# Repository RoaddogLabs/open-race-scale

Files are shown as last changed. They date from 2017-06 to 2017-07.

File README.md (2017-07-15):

# open-race-scale
# 
This is the Roaddog Labs fork of Open Race Scale, the open hardware
race car scale from Andrew Jenkins at
https://github.com/jenkinsracing/open-race-scale used under OSHWA and
LGPL 3.0 license.  [Original README.md](orig_README.md)

This fork deals with hardware implementation, hardware packaging and
PCB/PCBA design and fabrication.  This fork uses the software/firmware
from the upstream fork.  Please issue software/firmware pull requests to
the upstream repo.  Pull requests for hardware implementation in this
fork are more than welcome.

The `electrical` dir contains circuit designs and PCB/PCBA info.  It
includes the reference design from the upstream master that uses Chengbo HX711 carriers, a Pi Zero W
based control board with integrated HX711 load cell amps (no carriers) and Pi Hat design using Sparkfun HX711 formfactor carriers.

The `mechanical` dir contains a reference scale pad design and enclosure designs for the various controller boards.

Original designs from Roaddog Labs Ltd are released per the Open Source
Hardware Association guidelines for open source hardware at
http://www.oshwa.org/definition/.

Material specific to the components and documentation that is not
derived from other sources are released under the Creative Commons
Attribution 4.0 International license.

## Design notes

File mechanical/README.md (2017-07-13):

### Open Race Scale Mechanical Parts

This includes a 3D printed enclosure for the Open Race Scale control board as well as scale pads.

***THIS DESIGN IS NOT YET VALIDATED***

Forked from https://github.com/jenkinsracing/open-race-scale by Andrew Jenkins license OSHW/public domain, software LGPL 2.0.

Original designs from Roaddog Labs Ltd are released per the Open Source
Hardware Association guidelines for open source hardware at
http://www.oshwa.org/definition/.

Material specific to the components and documentation that is not
derived from other sources are released under the Creative Commons
Attribution 4.0 International license.

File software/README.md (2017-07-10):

### This is the Roaddog Labs fork of Open Race Scale

Current hardware deployment is Raspbian Jesse built for arm7l.  Install using current release (or NOOBS) and run `sudo apt-get update`.  Reminder: Raspbian requires root to install, use sudo. 

Using default user pi code is deployed to ~pi, adjust your PYTHONPATH accordingly

This release requires python3, dependencies to be built with python3

Change bool value of sim to False  `sim = False` in main.py to deploy on
RPi hardware.  Hardware integration is currently in development, in run mode there may be fatal errors.

The software is currently designed in two parts. 1. Core - The core code
runs on the RPi3 and communicates with HX711 to receive weights from the
loadcells. It does limited calculations with those weights to give
standard weighing information. This data (will be) published to a
Bluetooth RFComm channel for clients to read. 2. App - The app code at
this time runs a local GUI which instantiates the core code. Bluetooth
is currently not implemented, however in the future this code will be
reused in two ways: local mode for a GUI running on the same RPi3 that
is connected to the loadcells, and client mode where the app will
operate as a Bluetooth client on a smart phone.

Core Dependencies: 

pybluez

App Dependencies:

kivy 

pygame, python3 version in Raspbian dist

cython

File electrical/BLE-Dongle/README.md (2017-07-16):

# open-race-scale
# 

This is a Bluetooth LE dongle that transmits data from the scale pad to the mobile device.

There is no software or firmware at this time.  This is a reference design using an Adafruit Bluefruit nRF52 module and a Chenbo HX711 module.  This board uses pins A0 for the d_out from the HX711 and pin A1 for the S_CLK to the HX711.  If/when this changes in the software the board will be updated.

This is the Roaddog Labs fork of Open Race Scale, the open hardware
race car scale from Andrew Jenkins at
https://github.com/jenkinsracing/open-race-scale used under OSHWA and
LGPL 3.0 license.  

Original designs from Roaddog Labs Ltd are released per the Open Source
Hardware Association guidelines for open source hardware at
http://www.oshwa.org/definition/.

Material specific to the components and documentation that is not
derived from other sources are released under the Creative Commons
Attribution 4.0 International license.

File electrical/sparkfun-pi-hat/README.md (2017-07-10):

### Open Race Scale Sparkfun HX711 carrier board control board

***THIS BOARD IS NOT YET VALIDATED***

This is an early release version of the control board using Sparkfun HX711 carriers ( https://www.sparkfun.com/products/13879?_ga=2.157347578.176752245.1497484451-1883676811.1497484451 ).  It is not yet ready for production.  It has passed Eagle ERC and DRC for Seeed Fusion PCB.

Forked from https://github.com/jenkinsracing/open-race-scale by Andrew Jenkins license OSHW/public domain, software LGPL 2.0.

Original designs from Roaddog Labs Ltd are released per the Open Source
Hardware Association guidelines for open source hardware at
http://www.oshwa.org/definition/.

Material specific to the components and documentation that is not
derived from other sources are released under the Creative Commons
Attribution 4.0 International license.

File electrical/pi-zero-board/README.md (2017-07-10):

### Open Race Scale Pi Zero based control board

***THIS BOARD IS NOT YET VALIDATED***

This is an early release version of the integrated control board.  It is not yet ready for production.  It has passed Eagle ERC and DRC for Seeed Fusion PCB.

Forked from https://github.com/jenkinsracing/open-race-scale by Andrew Jenkins license OSHW/public domain, software LGPL 2.0.

Uses Pi Zero and integrated HX711 amps instead of Pi 3 and HX711 carrier
boards.

HX711 circuit from Sparkfun Load Cell Amplifier https://github.com/sparkfun/HX711-Load-Cell-Amplifier/tree/V_1.1 license public domain/OSHW

Original designs from Roaddog Labs Ltd are released per the Open Source
Hardware Association guidelines for open source hardware at
http://www.oshwa.org/definition/.

Material specific to the components and documentation that is not
derived from other sources are released under the Creative Commons
Attribution 4.0 International license.

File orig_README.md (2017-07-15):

# open-race-scale
### Open Source Racecar Scale  
Four load cell scale controller for weighing cars using HX711 load cell module and Raspberry Pi platform. User interface will be via Bluetooth and smart phone app. The overall cost target goal for a complete car weighing system is under $230, at least 75% cheaper than commerically available car scales.
  
### Roadmap  
* Prototype electrical design as Raspberry Pi 3 Hat -> in progress  
* Create simple mechanical design for load cells -> in progress  
* Create Android/iOS app that will connect to the Rasberry Pi 3 to reccive live scale data (via bluetooth)  
* Add advanced features for storing weights for comparision  
* Add option of LCD screen directly on the Raspberry Pi 3  
* Get feedback and feature requests  
  
### Design
Electrical Design

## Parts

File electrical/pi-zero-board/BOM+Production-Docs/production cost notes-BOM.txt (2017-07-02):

BOM for open race scale pi zero board with and without carriers

Partlist exported from /Users/dave/Documents/SparkFun_HX711_Load_Cell_v11/SparkFun_HX711_Load_Cell_v11.sch at 6/15/17 5:34 PM

Part      Value                      Device                     Package                           Description                          PROD_ID     VALUE   
4xC1        0.1uF                      0.1UF-25V-5%(0603)         0603-CAP                          CAP-08604                            CAP-08604   0.1uF   
4xC2        0.1uF                      0.1UF-25V-5%(0603)         0603-CAP                          CAP-08604                            CAP-08604   0.1uF   
4xC3        0.1uF                      0.1UF-25V-5%(0603)         0603-CAP                          CAP-08604                            CAP-08604   0.1uF   
4xC4        0.1uF                      0.1UF-25V-5%(0603)         0603-CAP                          CAP-08604                            CAP-08604   0.1uF   
4xC5        0.1uF                      0.1UF-25V-5%(0603)         0603-CAP                          CAP-08604                            CAP-08604   0.1uF   
4xC6        10uF                       10UF50V20%(1210)           1210                              CAP-09824                            CAP-09824   10uF    
4xC7        10uF                       10UF50V20%(1210)           1210                              CAP-09824                            CAP-09824   10uF    
4xJ1                                   M05PTH                     1X05                              Header 5                                                 
4xJP2                                  M02PTH                     1X02                              Standard 2-pin 0.1" header. Use with                     
4xJP4                                  M05PTH                     1X05                              Header 5                                                 
4xL1        3.3uH                      INDUCTOR0805-IND           0805                              Inductors                            NDUC-13076          
4xQ1        MMBT4403                   TRANSISTOR_PNPMMBT4403     SOT23-3                           Generic PNP BJT                      TRANS-09245 MMBT4403
4xR1        20k                        20KOHM1/10W1%(0603)        0603-RES                          RES-09383                            RES-09383   20k     
4xR2        8.2K                       8.2KOHM-1/10W-5%(0603)     0603-RES                          RES-10646                            RES-10646           
4xR3        100                        100OHM-1/10W-1%(0603)      0603-RES                          RES-07863                            RES-07863   100     
4xR4        100                        100OHM-1/10W-1%(0603)      0603-RES                          RES-07863                            RES-07863   100     
4xR5        10K                        10KOHM-1/10W-1%(0603)0603  0603-RES                          RES-00824                            RES-00824   10K     
SJ2                                  JUMPER-PAD-2-NC_BY_TRACE   PAD-JUMPER-2-NC_BY_TRACE_YES_SILK                                                          
                                                                                 
xxU1        HX711                      HX711HX711                 SO16                           Kynix http://www.kynix.com/Detail/627064/HX711.html                                        IC-12445    HX711   

Per the v1r2 board
parts kitted from Digikey for a single board (carriers) ors load cell amp #5313337 $11.03
HX711 @ .40 each from Kynix http://www.kynix.com/Detail/627064/HX711.html
pi gpio connector @1.50 ea from Adafruit  https://www.adafruit.com/product/2222 (pi zero needs 90* connector plus header pins)
4 x carrier board prototype @ .49 (panelized for 4 each per board) Seeed
1 x main board 2 layer prototype @ .49 each  Seeed

1 x main board 4 layer  @ 4.90 each  Seeed (we can cut that down with higher qty and another vendor approx $2.50 in 100 ql1ty

plug terminals are the main pain point on pricing

produced carrier boards with main board ($43.29 name brand terminals), ($21.09 import brand terminals) ($19.84 pin headers) no fab, stencil cost or shipping  (source less expensive pluggable blocks)
produced main board with import carrier boards ($40.26 name brand terminals) ($18.06 import brand terminals) ($16.81 pin headers)  minimal through hole assembly

produced integrated main board in 4 layer approx ($50 name brand terminals) ($27 import brand terminals) ($24 pin headers) no fab, stencil cost or shipping

pi zero w @10 Adafruit
pi 3 @39.95 Adafruit

pcba quotes

carriers
seeed  US$374.00 plus shipping for 100 carriers per sparkfun spec not panelized (not confirmed, no cost for hx711 and C5,C6, perhaps US$100 more)
bitelle/7pcb  US$642.27 plus shipping  for 100 carriers per sparkfun spec not panelized (not confirmed, no cost for hx711 yet)

integrated board
seeed need to finish gerber for quote
bitelle/7pcb  estimate US$ 452.76 plus shipping for 10 prototype no connectors and cost TBA on hx711.  Add US$200 for production quality.

bitelle/7pcb  estimate US$ 350.00 plus shipping for 5 prototype no connectors and cost TBA on hx711.

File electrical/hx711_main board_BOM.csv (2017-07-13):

Designator | SKU | Qty
40 pos 2 row socket header-tall | 1992 | 1 | https://www.pololu.com/product/2749 | 2.95 | 2.95
2 pos socket header 2.54mm | 1012 | 1 | https://www.pololu.com/product/1012 | 0.29 | 0.29
4 pos socket header 2.54mm | 1014 | 4 | https://www.pololu.com/product/1014 | 0.39 | 1.56
6 pos socket header 2.54m | 1016 | 4 | https://www.pololu.com/product/1016 | 0.49 | 1.96
2 pos screw terminal 3.5mm | 2444 | 8 | https://www.pololu.com/product/2444 | 0.375 | 3.00
40 pos breakaway pin header | 965 | 1 | https://www.pololu.com/product/965 | 0.75 | 0.75
2 pos shorting block 2.54mm | 970 | 4 | https://www.pololu.com/product/970 | 0.19 | 0.76
Raspberry Pi Model 3 | 3055 | 1 | https://www.pololu.com/product/2759 | 39.95 | 39.95
HX711 carrier boards | CHENBO | 4 | https://www.amazon.com/dp/B01D1FECVI/ref=cm_sw_r_cp_dp_T1_z.gozbGZ390B2 | 01.997 | 08.00
bare main board pcb | SEEED | 1 |  | .5 | 0.50

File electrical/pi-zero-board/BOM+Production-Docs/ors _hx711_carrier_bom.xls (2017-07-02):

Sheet: 4 x carriers
Digi-Key Part Number | Manufacturer | Manufacturer Part Number | Customer Reference | Quantity 1 | Quantity 2 | Quantity 3 | Mfg Std Lead Time | Description | Comments | RoHS Status | Lead Free Status | REACH Status
311-1777-1-ND | YAGEO (VA) | CC0603JRX7R8BB104 |  | 100 | 0 | 0 | 20 Weeks | CAP CER 0.1UF 25V X7R 0603 | Alternate Packaging Exists | RoHS Compliant | Lead free | Unaffected Jan-2017
311-3470-1-ND | YAGEO (VA) | CC1210ZKY5V9BB106 |  | 12 | 0 | 0 | 21 Weeks | CAP CER 10UF 50V Y5V 1210 | Alternate Packaging Exists | RoHS Compliant | Lead free | Unaffected
MMBT4403-FDICT-ND | DIODES INCORPORATED (VA) | MMBT4403-7-F |  | 10 | 0 | 0 | 12 Weeks | TRANS PNP 40V 0.6A SOT23-3 | No delivery date available | RoHS Compliant | Lead free | Unaffected Jan-2017
311-20.0KHRCT-ND | YAGEO (VA) | RC0603FR-0720KL |  | 10 | 0 | 0 | 22 Weeks | RES SMD 20K OHM 1% 1/10W 0603 | Alternate Packaging Exists | RoHS Compliant | Lead free | Unaffected Jan-2017
311-8.20KHRCT-ND | YAGEO (VA) | RC0603FR-078K2L |  | 10 | 0 | 0 | 22 Weeks | RES SMD 8.2K OHM 1% 1/10W 0603 | Alternate Packaging Exists | RoHS Compliant | Lead free | Unaffected Jan-2017
311-100HRCT-ND | YAGEO (VA) | RC0603FR-07100RL |  | 10 | 0 | 0 | 22 Weeks | RES SMD 100 OHM 1% 1/10W 0603 | Alternate Packaging Exists | RoHS Compliant | Lead free | Unaffected Jan-2017
311-10.0KHRCT-ND | YAGEO (VA) | RC0603FR-0710KL |  | 10 | 0 | 0 | 22 Weeks | RES SMD 10K OHM 1% 1/10W 0603 | Alternate Packaging Exists | RoHS Compliant | Lead free | Unaffected Jan-2017
732-5318-ND | WURTH ELECTRONICS INC | 61300511121 |  | 10 | 0 | 0 | 15 Weeks | CONN HEADER 5 POS 2.54 |  | RoHS Compliant | Lead free | Unaffected Jun-2016
732-5315-ND | WURTH ELECTRONICS INC | 61300211121 |  | 5 | 0 | 0 | 15 Weeks | CONN HEADER 2 POS 2.54 |  | RoHS Compliant | Lead free | Unaffected Jun-2016
445-6394-1-ND | TDK CORPORATION (VA) | MLZ2012A3R3WT000 |  | 5 | 0 | 0 | 10 Weeks | FIXED IND 3.3UH 450MA 340 MOHM | Alternate Packaging Exists | RoHS Compliant | Lead free | Unaffected Jan-2017
n/a | Seeed | n/a |  | 1

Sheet: seeed bom carrier
c1,c2,c3,c4,c5 | CC0603JRX7R8BB104 | 5
c6,c7 | CC1210ZKY5V9BB106 | 2
l1 | MLZ2012A3R3WT000 | 1
q1 | MMBT4403-7-F | 1
r1 | RC0603FR-0720KL | 1
r2 | RC0603FR-078K2L | 1
r3,r4 | RC0603FR-07100RL | 1
r5 | RC0603FR-0710KL | 1
u1 | hx711 | 1

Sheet: main board
ors main carrier board
 |  |  |  |  |  | revised scale pad connectors
 |  |  |  |  |  | pin headers
2 | 40 pin break away headers | pololu | 0.75 | 1.5 |  | 3 | 40 pin break away headers | pololu | 0.75 | 2.25
1 | 2 x 20 female header | adafruit | 1.5 | 1.5 |  | 1 | 2 x 20 female header | adafruit | 1.5 | 1.5
1 | 1 x 2 female header | pololu | 0.29 | 0.29 |  | 1 | 1 x 2 female header | pololu | 0.29 | 0.29
4 | 1 x 4 female header | pololu | 0.39 | 1.56 |  | 4 | 1 x 4 female header | pololu | 0.39 | 1.56
4 | 1 x 6 female header | pololu | 0.49 | 1.96 |  | 4 | 1 x 6 female header | pololu | 0.49 | 1.96
4 | jumper blocks | pololu | 0.19 | 0.76 |  | 4 | jumper blocks | pololu | 0.19 | 0.76
4 | plugable screw terminal M | Phoenix | 1.7 | 6.8 |  |  |  |  | 0 | 0
4 | plugable screw terminal F | Phoenix | 4.35 | 17.4 |  |  |  |  | 0 | 0
 |  |  |  | 0 |  |  |  |  |  | 0
 |  |  |  | 0 |  |  |  |  |  | 0
1 | board | seeed | 0.49 | 0.49 |  | 1 | board | seeed | 0.49 | 0.49
 |  |  |  | 32.26 |  |  |  |  |  | 8.81
1 | set import HX711 carriers | Amazon | 8 | 8 |  | 1 | set import HX711 carriers | Amazon | 8 | 8
 |  |  |  | 40.26 |  |  |  |  |  | 16.81
revised scale pad connectors
import 3.5 plug or screw terminals
2 | 40 pin break away headers | pololu | 0.75 | 1.5
1 | 2 x 20 female header | adafruit | 1.5 | 1.5
1 | 1 x 2 female header | pololu | 0.29 | 0.29
4 | 1 x 4 female header | pololu | 0.39 | 1.56
4 | 1 x 6 female header | pololu | 0.49 | 1.96
4 | jumper blocks | pololu | 0.19 | 0.76
4 | plugable screw terminal M | import | 0.25 | 1 | *moq
4 | plugable screw terminal F | import | 0.25 | 1 | *moq
 |  |  |  | 0
 |  |  |  | 0
1 | board | seeed | 0.49 | 0.49
 |  |  |  | 10.06
1 | set import HX711 carriers | Amazon | 8 | 8
 |  |  |  | 18.06

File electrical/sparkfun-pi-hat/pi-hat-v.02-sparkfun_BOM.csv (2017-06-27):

Designator | Pololu SKU | Qty
J1 | 1037 | 1 | https://www.pololu.com/product/1037
J2,J3,J4,J5,J6,J7,J8,J9 | 1015 | 8 | https://www.pololu.com/product/1015
J10,J11,J12,J13 | 965 | 1 | https://www.pololu.com/product/965

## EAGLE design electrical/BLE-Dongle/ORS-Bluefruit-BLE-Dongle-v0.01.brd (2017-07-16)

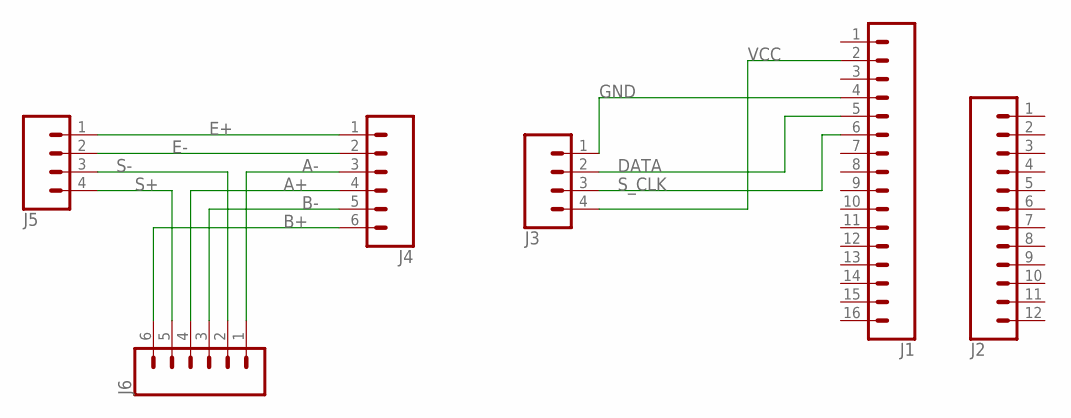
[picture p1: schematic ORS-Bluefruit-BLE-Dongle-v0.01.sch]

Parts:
J1: CONN_16; 1X16
J2: CONN_12; 1X12
J3: CONN_04; 1X04
J4, J6: CONN_06SILK_FEMALE_PTH; 1X06
J5: CONN_04SCREW; SCREWTERMINAL-3.5MM-4

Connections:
A+: J4.4, J6.4
A-: J4.3, J6.1
B+: J4.6, J6.6
B-: J4.5, J6.3
DATA: J1.5, J3.2
E+: J4.1, J5.1
E-: J4.2, J5.2
GND: J1.4, J3.1
S+: J5.4, J6.5
S-: J5.3, J6.2
S_CLK: J1.6, J3.3
VCC: J1.2, J3.4

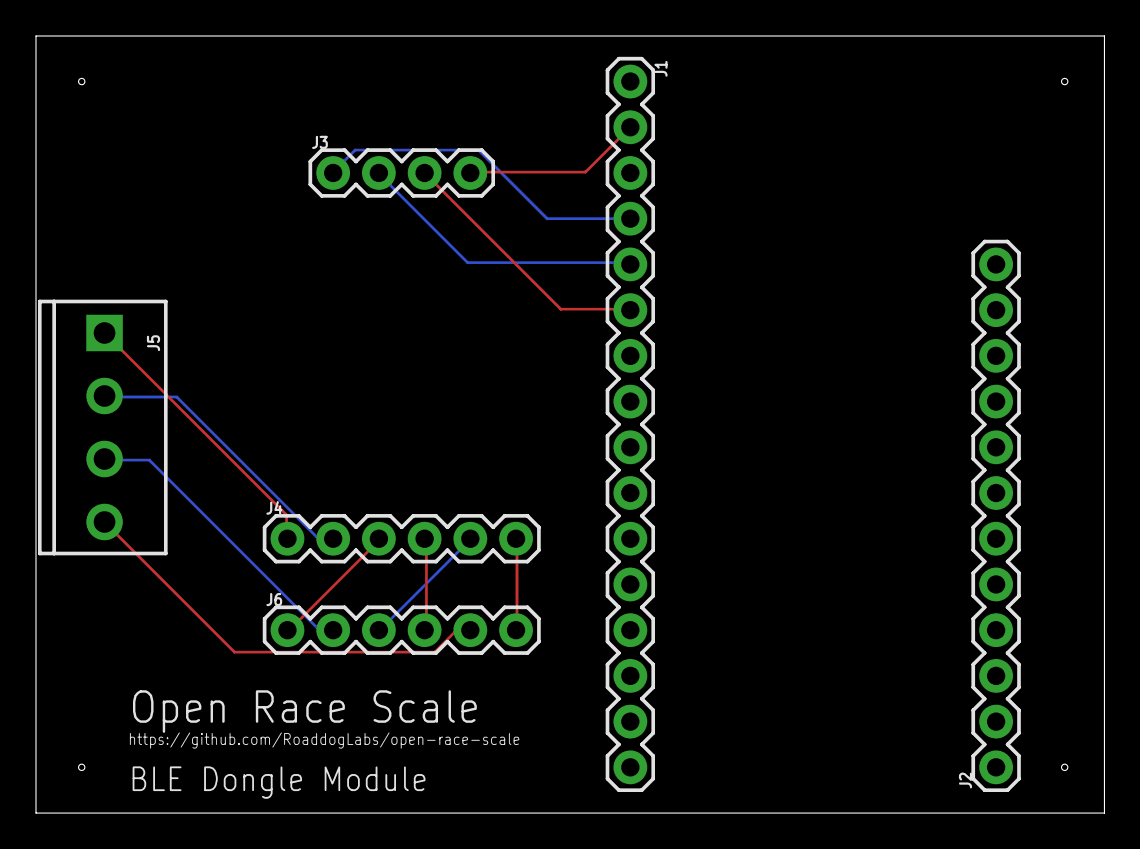
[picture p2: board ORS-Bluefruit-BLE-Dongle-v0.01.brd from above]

Board: 2 copper layers, 59.4 x 43.2 mm, 6 parts (0 on the bottom side), 12 nets.

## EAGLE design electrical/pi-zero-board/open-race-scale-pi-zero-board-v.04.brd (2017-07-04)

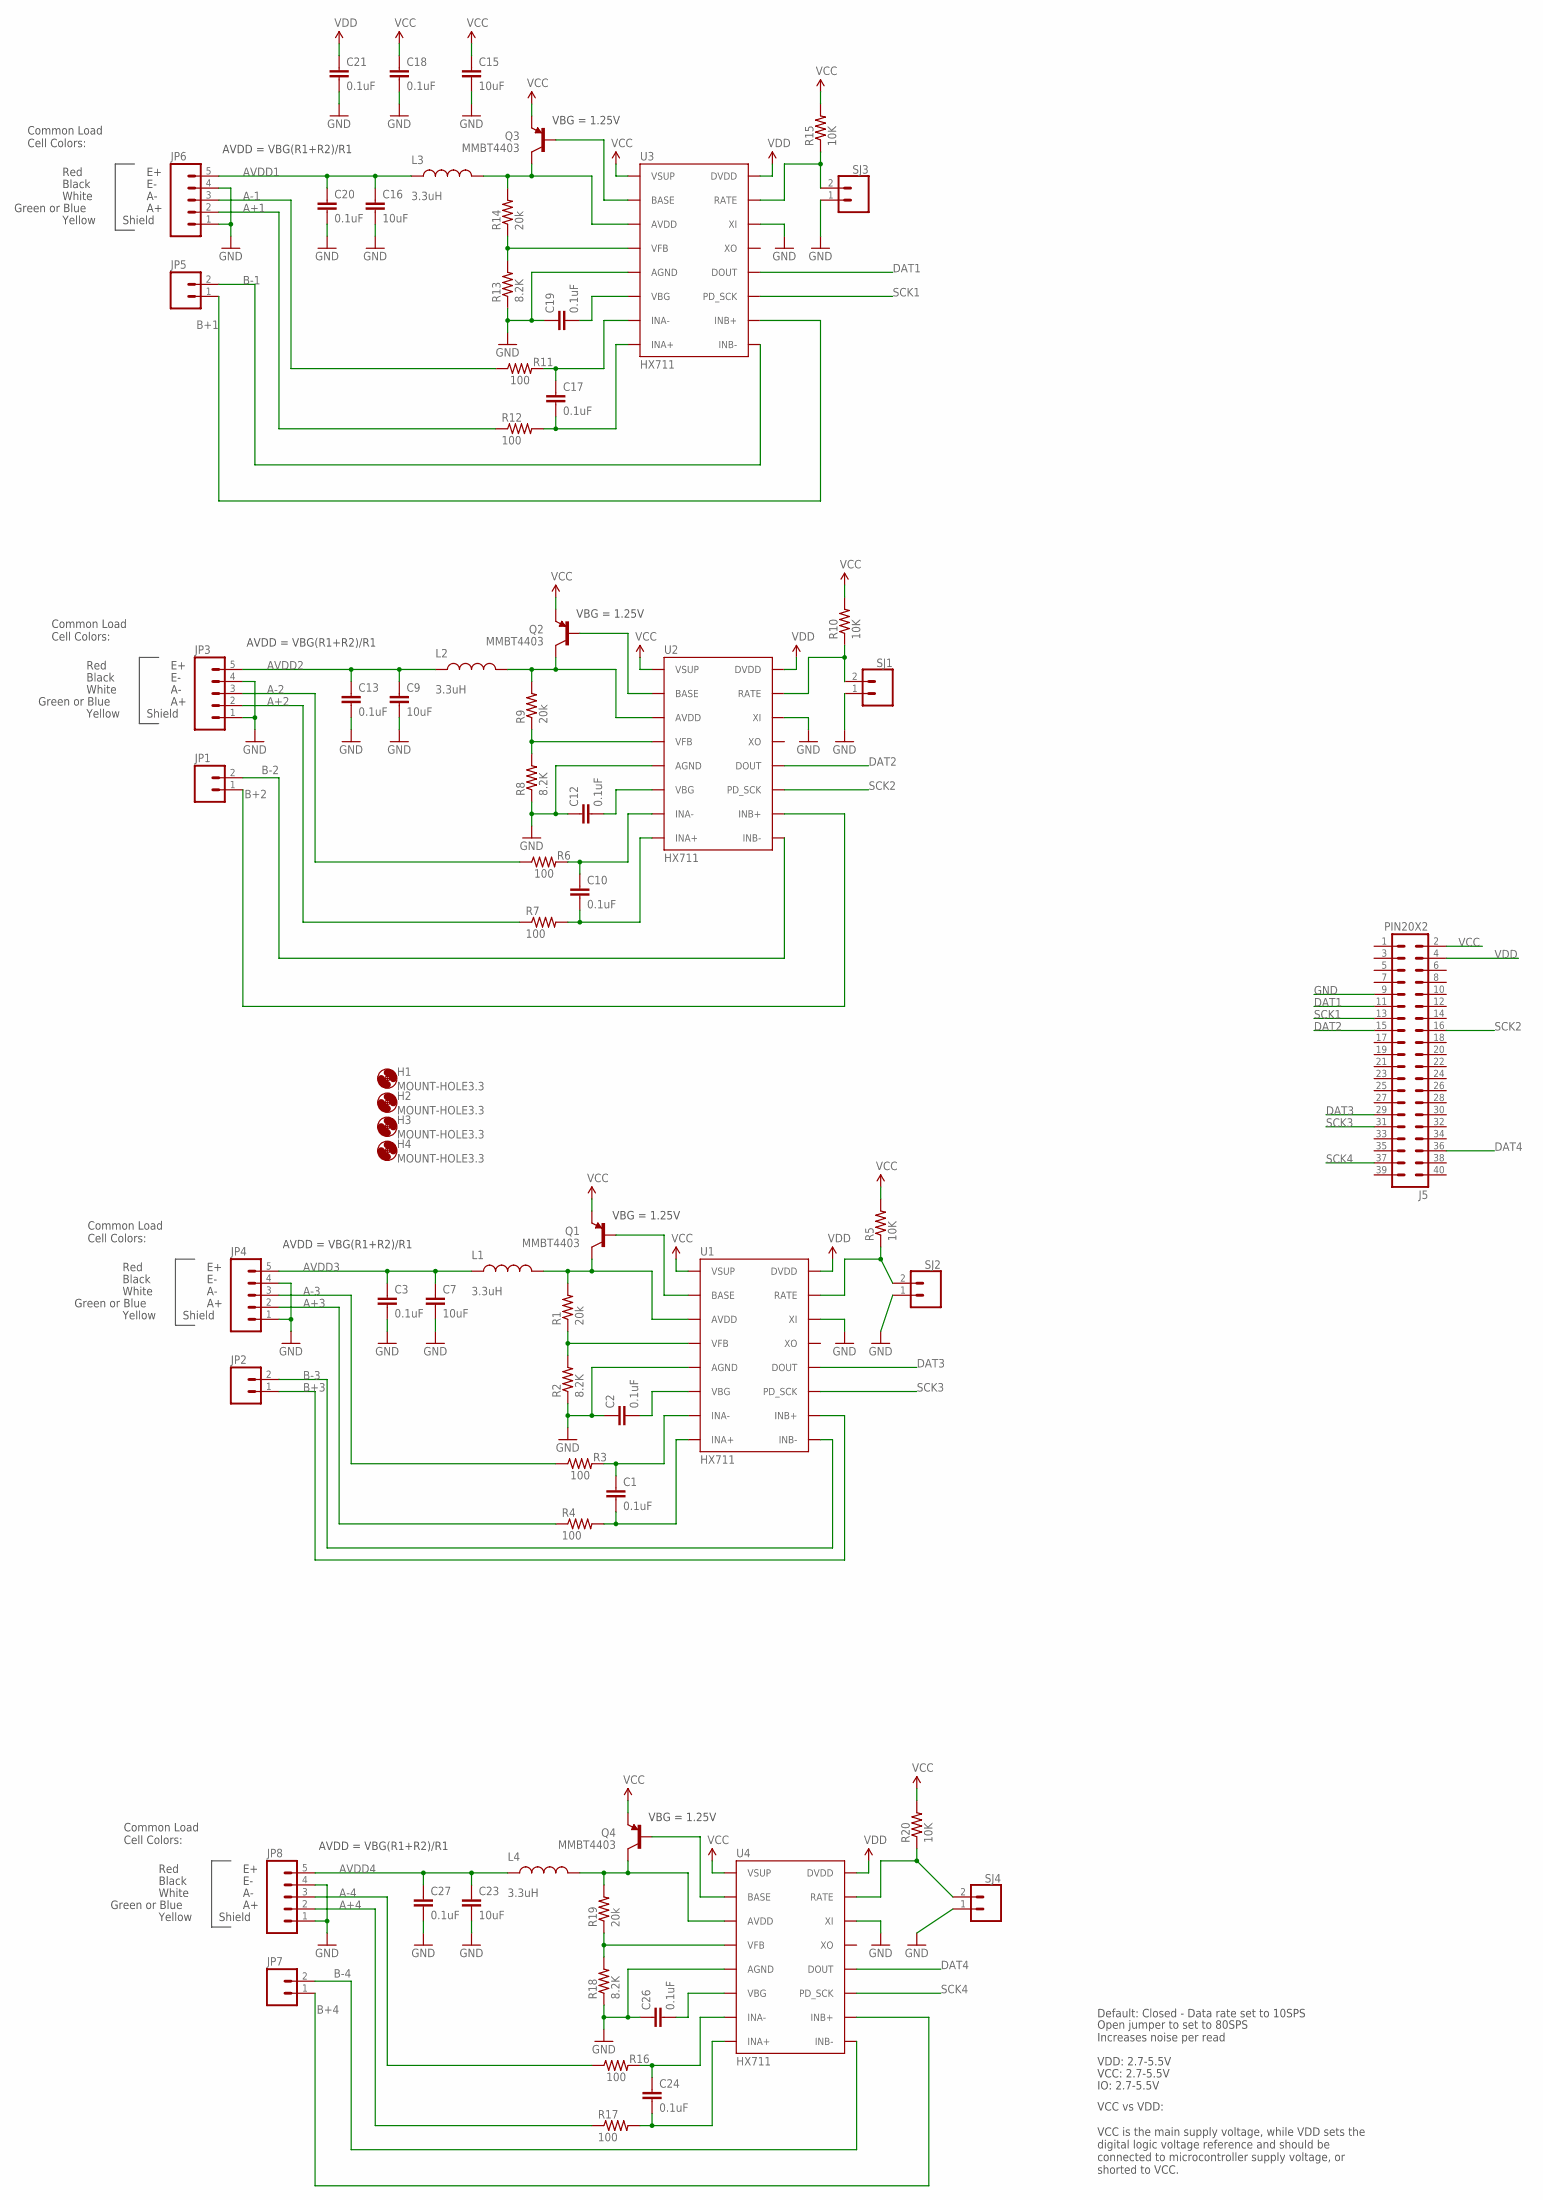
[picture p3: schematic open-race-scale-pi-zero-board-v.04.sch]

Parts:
C1, C2, C3, C10, C12, C13, C17, C18, C19, C20, C21, C24, C26, C27: 0.1uF; 0603-CAP
C7, C9, C15, C16, C23: 10uF; 1210
H1, H2, H3, H4: MOUNT-HOLE3.3; 3,3
J5: PIN20X2; PIN_20X2
JP1, JP2, JP5, JP7: M02PTH; 1X02@1
JP3, JP4, JP6, JP8: M05PTH; 1X05
L1, L2, L3, L4: 3.3uH; 0805
Q1, Q2, Q3, Q4: MMBT4403; SOT23-3
R1, R9, R14, R19: 20k; 0603-RES
R2, R8, R13, R18: 8.2K; 0603-RES
R3, R4, R6, R7, R11, R12, R16, R17: 100; 0603-RES
R5, R10, R15, R20: 10K; 0603-RES
SJ1, SJ2, SJ3, SJ4: CONN_02; 1X02
U1, U2, U3, U4: HX711; SO16

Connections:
A+1: JP6.2, R12.1
A+2: JP3.2, R7.1
A+3: JP4.2, R4.1
A+4: JP8.2, R17.1
A-1: JP6.3, R11.1
A-2: JP3.3, R6.1
A-3: JP4.3, R3.1
A-4: JP8.3, R16.1
AVDD1: C16.1, C20.1, JP6.5, L3.1
AVDD2: C9.1, C13.1, JP3.5, L2.1
AVDD3: C3.1, C7.1, JP4.5, L1.1
AVDD4: C23.1, C27.1, JP8.5, L4.1
B+1: JP5.1, U3.10 (INB+)
B+2: JP1.1, U2.10 (INB+)
B+3: JP2.1, U1.10 (INB+)
B+4: JP7.1, U4.10 (INB+)
B-1: JP5.2, U3.9 (INB-)
B-2: JP1.2, U2.9 (INB-)
B-3: JP2.2, U1.9 (INB-)
B-4: JP7.2, U4.9 (INB-)
DAT1: J5.11, U3.12 (DOUT)
DAT2: J5.15, U2.12 (DOUT)
DAT3: J5.29, U1.12 (DOUT)
DAT4: J5.36, U4.12 (DOUT)
GND: C2.1, C3.2, C7.2, C9.2, C12.1, C13.2, C15.2, C16.2, C18.2, C19.1, C20.2, C21.2, C23.2, C26.1, C27.2, J5.9, JP3.1, JP3.4, JP4.1, JP4.4, JP6.1, JP6.4, JP8.1, JP8.4, R2.1, R8.1, R13.1, R18.1, SJ1.1, SJ2.1, SJ3.1, SJ4.1, U1.5 (AGND), U1.14 (XI), U2.5 (AGND), U2.14 (XI), U3.5 (AGND), U3.14 (XI), U4.5 (AGND), U4.14 (XI)
unnamed: R5.1, SJ2.2, U1.15 (RATE)
unnamed: C1.1, R3.2, U1.7 (INA-)
unnamed: C1.2, R4.2, U1.8 (INA+)
unnamed: Q1.1 (B), U1.2 (BASE)
unnamed: L1.2, Q1.3 (C), R1.2, U1.3 (AVDD)
unnamed: R1.1, R2.2, U1.4 (VFB)
unnamed: C2.2, U1.6 (VBG)
unnamed: R8.2, R9.1, U2.4 (VFB)
unnamed: C12.2, U2.6 (VBG)
unnamed: C17.1, R11.2, U3.7 (INA-)
unnamed: C17.2, R12.2, U3.8 (INA+)
unnamed: Q4.1 (B), U4.2 (BASE)
unnamed: R18.2, R19.1, U4.4 (VFB)
unnamed: C26.2, U4.6 (VBG)
unnamed: L4.2, Q4.3 (C), R19.2, U4.3 (AVDD)
unnamed: R20.1, SJ4.2, U4.15 (RATE)
unnamed: C24.1, R16.2, U4.7 (INA-)
unnamed: C24.2, R17.2, U4.8 (INA+)
unnamed: Q2.1 (B), U2.2 (BASE)
unnamed: L2.2, Q2.3 (C), R9.2, U2.3 (AVDD)
unnamed: R10.1, SJ1.2, U2.15 (RATE)
unnamed: C10.1, R6.2, U2.7 (INA-)
unnamed: C10.2, R7.2, U2.8 (INA+)
unnamed: Q3.1 (B), U3.2 (BASE)
unnamed: R13.2, R14.1, U3.4 (VFB)
unnamed: C19.2, U3.6 (VBG)
unnamed: L3.2, Q3.3 (C), R14.2, U3.3 (AVDD)
unnamed: R15.1, SJ3.2, U3.15 (RATE)
SCK1: J5.13, U3.11 (PD_SCK)
SCK2: J5.16, U2.11 (PD_SCK)
SCK3: J5.31, U1.11 (PD_SCK)
SCK4: J5.37, U4.11 (PD_SCK)
VCC: C15.1, C18.1, J5.2, Q1.2 (E), Q2.2 (E), Q3.2 (E), Q4.2 (E), R5.2, R10.2, R15.2, R20.2, U1.1 (VSUP), U2.1 (VSUP), U3.1 (VSUP), U4.1 (VSUP)
VDD: C21.1, J5.4, U1.16 (DVDD), U2.16 (DVDD), U3.16 (DVDD), U4.16 (DVDD)

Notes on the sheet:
VBG = 1.25V
AVDD = VBG(R1+R2)/R1
Red
Black
White
Green or Blue
Common Load Cell Colors:
Shield
Yellow
VCC: 2.7-5.5V
Default: Closed - Data rate set to 10SPS
Open jumper to set to 80SPS Increases noise per read
IO: 2.7-5.5V
VDD: 2.7-5.5V
VCC vs VDD: VCC is the main supply voltage, while VDD sets the digital logic voltage reference and should be connected to microcontroller supply voltage, or shorted to VCC.

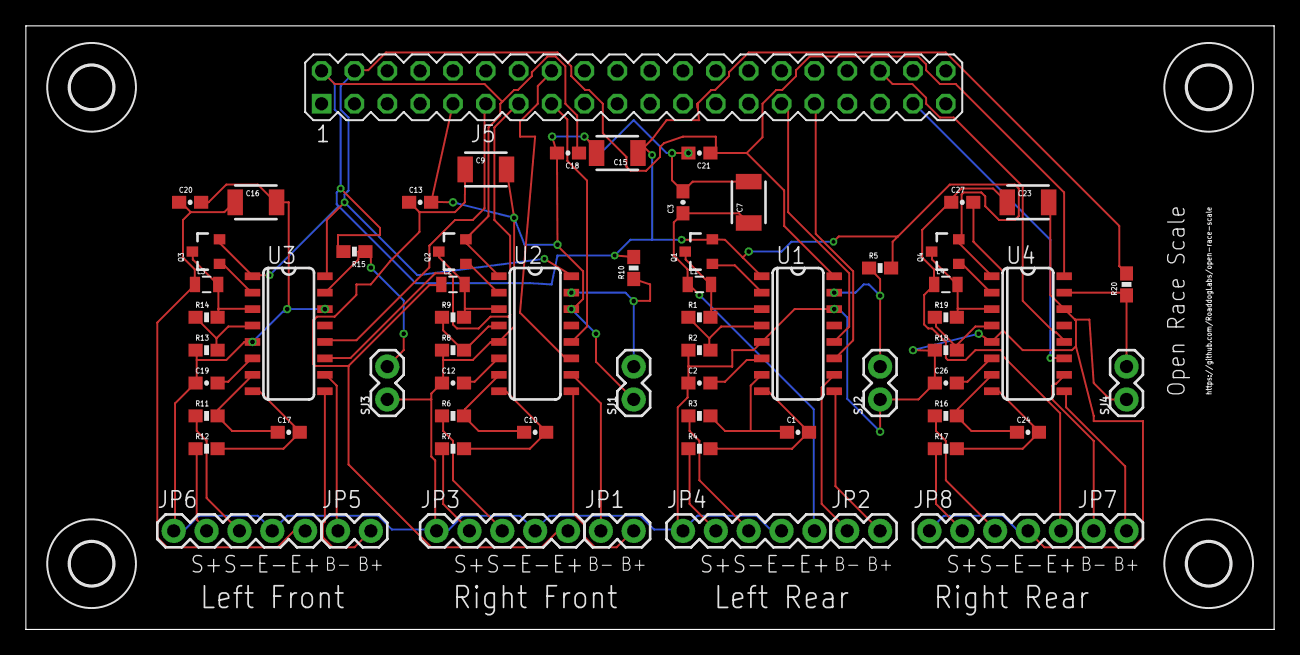
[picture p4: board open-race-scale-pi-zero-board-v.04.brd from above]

Board: 2 copper layers, 96.5 x 46.7 mm, 68 parts (0 on the bottom side), 59 nets.

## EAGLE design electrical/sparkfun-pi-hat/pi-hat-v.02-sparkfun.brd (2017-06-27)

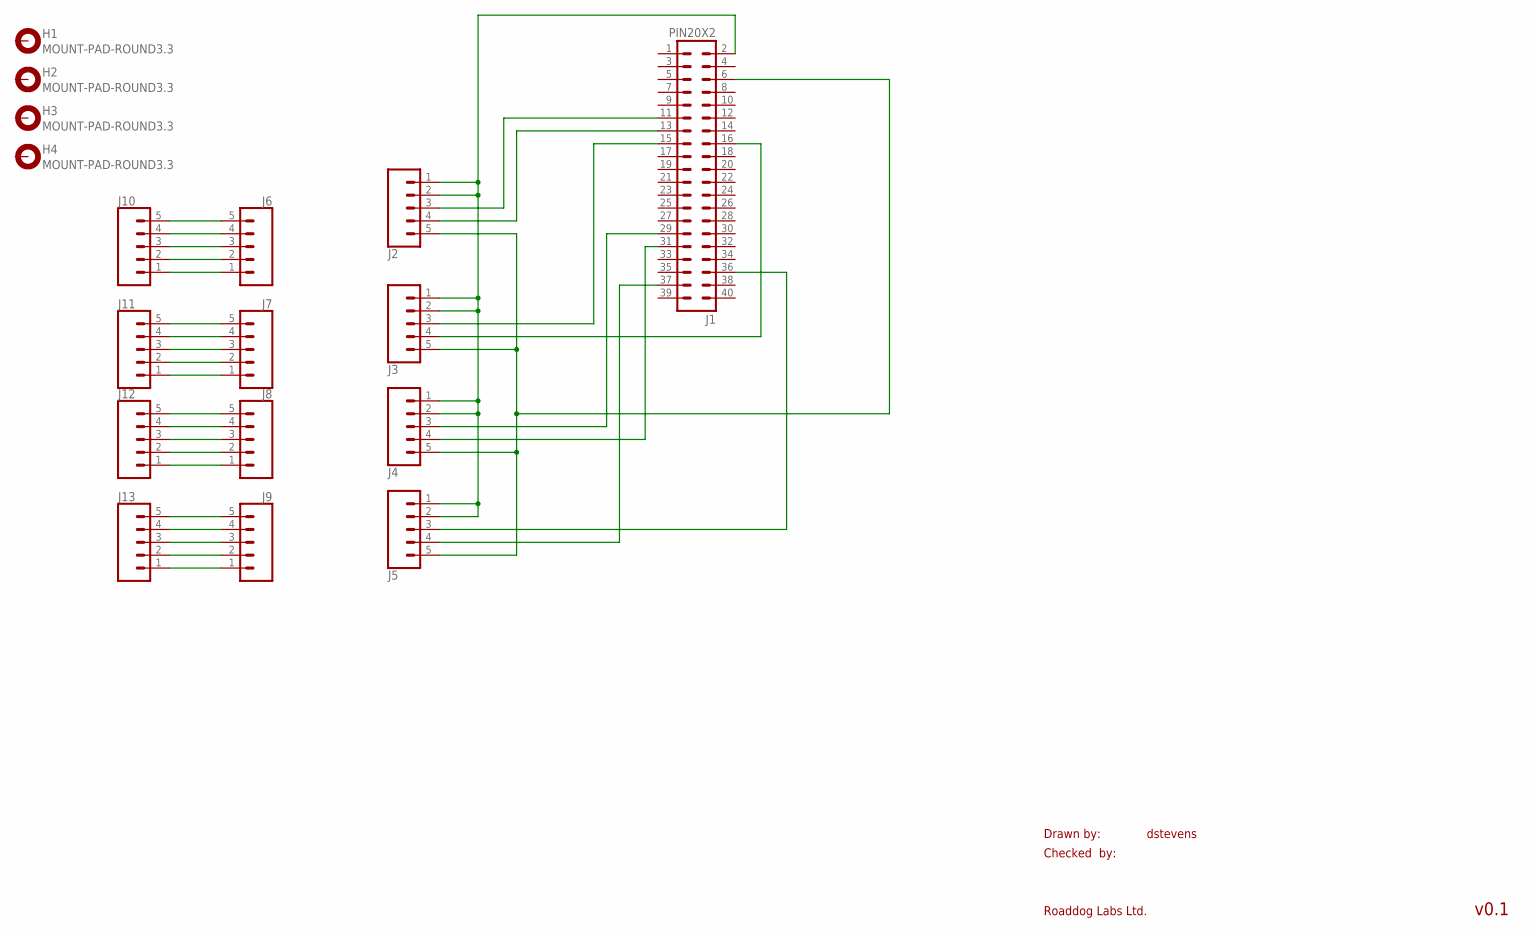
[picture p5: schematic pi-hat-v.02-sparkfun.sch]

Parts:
H1, H2, H3, H4: MOUNT-PAD-ROUND3.3; 3,3-PAD
J1: PIN20X2; PIN_20X2
J2, J3, J4, J5, J6, J7, J8, J9, J10, J11, J12, J13: CONN_05; 1X05

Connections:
unnamed: J6.5, J10.5
unnamed: J6.4, J10.4
unnamed: J6.3, J10.3
unnamed: J6.2, J10.2
unnamed: J6.1, J10.1
unnamed: J7.5, J11.5
unnamed: J7.4, J11.4
unnamed: J7.3, J11.3
unnamed: J7.2, J11.2
unnamed: J7.1, J11.1
unnamed: J8.5, J12.5
unnamed: J8.4, J12.4
unnamed: J8.3, J12.3
unnamed: J8.2, J12.2
unnamed: J8.1, J12.1
unnamed: J9.5, J13.5
unnamed: J1.2, J2.1, J2.2, J3.1, J3.2, J4.1, J4.2, J5.1, J5.2
unnamed: J1.6, J2.5, J3.5, J4.5, J5.5
unnamed: J1.11, J2.3
unnamed: J1.13, J2.4
unnamed: J1.15, J3.3
unnamed: J1.16, J3.4
unnamed: J1.37, J5.4
unnamed: J1.36, J5.3
unnamed: J1.31, J4.4
unnamed: J1.29, J4.3
unnamed: J9.4, J13.4
unnamed: J9.3, J13.3
unnamed: J9.2, J13.2
unnamed: J9.1, J13.1

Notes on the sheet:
Drawn by:
Checked by:
Roaddog Labs Ltd.
dstevens
v0.1

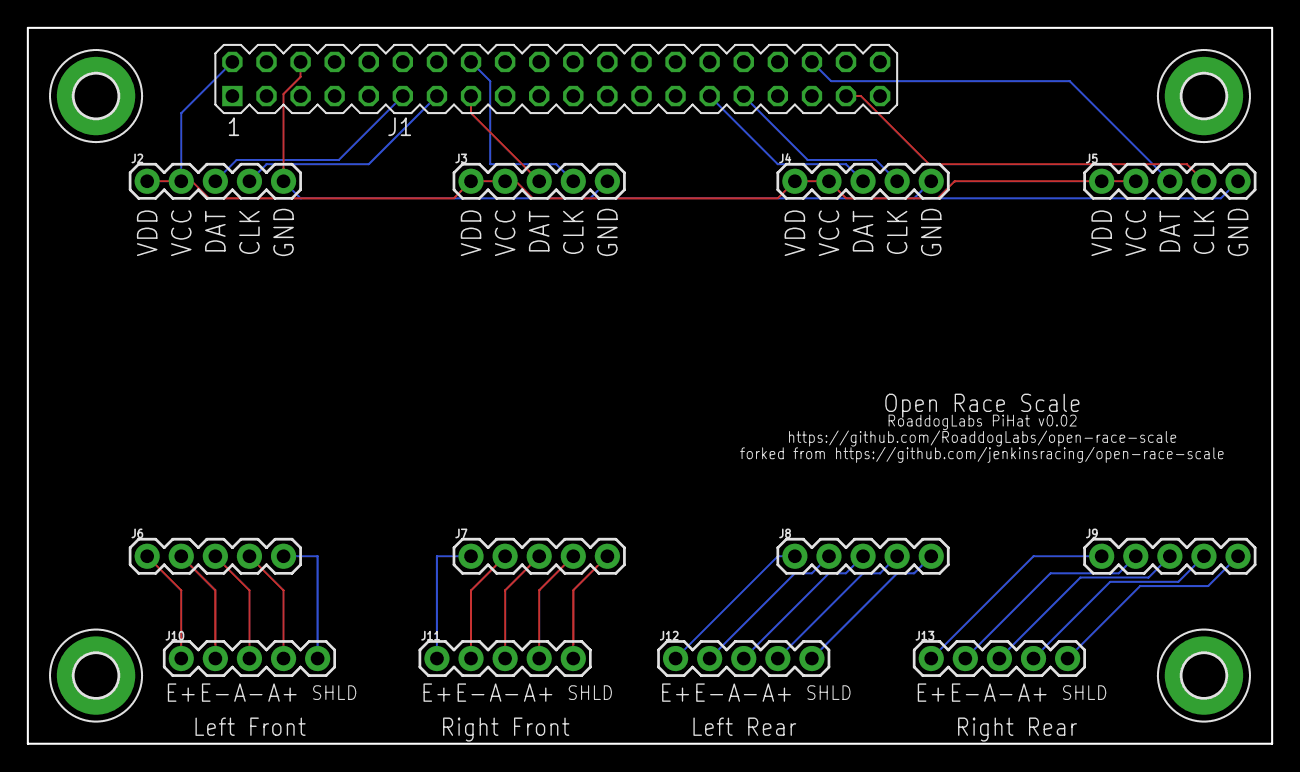
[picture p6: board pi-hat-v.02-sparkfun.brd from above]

Board: 2 copper layers, 92.7 x 53.3 mm, 17 parts (0 on the bottom side), 30 nets.

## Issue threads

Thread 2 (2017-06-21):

carrier topology needs revision to fit on pi hat

RoaddogLabs, 2017-06-21:
the Fritzing design does not fit on a spec pi hat
investigate different layout or increase pi hat size to non-standard

non-standard board will require different GPIO header to clear usb and ethernet
possible heat and rf issues in ports, investigate

pi hat specs at https://github.com/raspberrypi/hats

@jenkinsracing

[pi-hat-v.01.pdf](https://github.com/RoaddogLabs/open-race-scale/files/1090928/pi-hat-v.01.pdf)

RoaddogLabs, 2017-06-21:
resolved with jenkins fix on fritzing and dave fix on pi hat eagle

Closed 2017-06-21.

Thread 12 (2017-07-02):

pi zero board: replace sj w/ pin jumpers?

RoaddogLabs, 2017-07-02:
investigate replacing the solder jumpers with pin jumpers

RoaddogLabs, 2017-07-02:
replaced with pin jumpers
investigate different solder jumpers
sparkfun sj keep failing DRC

Closed 2017-07-04.

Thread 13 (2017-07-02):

pi zero board: jumpers for speed setting or separate connector?

RoaddogLabs, 2017-07-02:
what is the best way to use either speed channels on hx711?

jumpers like on 1st jenkins board rev

or

separate header pins like on 1st pi zero board rev

leaning toward jumpers like jenkins

RoaddogLabs, 2017-07-02:
rework design to use jumpers per jenkins design

RoaddogLabs, 2017-07-02:
check with @jenkinsracing for use cases requiring the second channel

RoaddogLabs, 2017-08-01:
will not provide access to second channel

no supporting information to support need to provide both channels

Closed 2017-08-01.

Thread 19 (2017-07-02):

pi zero board: scale sensor connectors

RoaddogLabs, 2017-07-02:
rework layout for order of connections
rework pin headers for 3.5 pitch screw terminal

RoaddogLabs, 2017-07-14:
won't fix, closing

Closed 2017-07-14.

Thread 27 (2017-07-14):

app rpi: kivy stalls when quit and relaunched

RoaddogLabs, 2017-07-14:
kivy stalls when ors page is exited on `provider sdl2`

python3 consumes 99% cpu

RoaddogLabs, 2017-07-14:
resuming with fg spawns 2 python3 procs that consume 100% cpu

resolves by killing procs or bring to foreground and exit

RoaddogLabs, 2017-07-14:
`pi@raspberrypi:~/open-race-scale/software/app $ python3 main.py
[INFO   ] [Logger      ] Record log in /home/pi/.kivy/logs/kivy_17-07-14_8.txt
[INFO   ] [Kivy        ] v1.10.1.dev0, git-287d3b6, 20170710
[INFO   ] [Python      ] v3.4.2 (default, Oct 19 2014, 13:31:11)
[GCC 4.9.1]
[INFO   ] [Factory     ] 194 symbols loaded
[INFO   ] [Image       ] Providers: img_tex, img_dds, img_sdl2, img_pil, img_gif (img_ffpyplayer ignored)
[INFO   ] [Text        ] Provider: sdl2
^C Traceback (most recent call last):
   File "main.py", line 193, in <module>
     sc = ScaleControl(simulate=sim)
   File "/home/pi/open-race-scale/software/core/corerp3.py", line 10, in __init__
     self.load_cells = {'FL': LoadCell(17, 27, simulate=simulate),
   File "/home/pi/open-race-scale/software/core/loadcell.py", line 25, in __init__
     self.driver = driver or HX711(dout_pin, pd_sck_pin)
   File "/home/pi/open-race-scale/software/core/hx711.py", line 27, in __init__
     self.set_gain(gain)
   File "/home/pi/open-race-scale/software/core/hx711.py", line 48, in set_gain
     self.read()
   File "/home/pi/open-race-scale/software/core/hx711.py", line 61, in read
     self.wait_for_ready()
   File "/home/pi/open-race-scale/software/core/hx711.py", line 51, in wait_for_ready
     while not self.is_ready():
   File "/home/pi/open-race-scale/software/core/hx711.py", line 30, in is_ready
     def is_ready(self):
 KeyboardInterrupt
[2]+  Terminated              python3 main.py`

RoaddogLabs, 2017-07-14:
can't replicate so far, did it twice but now runs

RoaddogLabs, 2017-07-15:
can't replicate over 24 hours, closing

Closed 2017-07-15.

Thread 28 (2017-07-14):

rpi hardware: exciter voltages not present on all boards

RoaddogLabs, 2017-07-14:
exciter voltages don't meter on all Chenbo boards

RoaddogLabs, 2017-07-14:
all but carrier 3 fixed, close this and open new for that one carrier

Closed 2017-07-14.

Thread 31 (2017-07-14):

rpi hardware: no exciter voltage #3

RoaddogLabs, 2017-07-14:
no exciter voltage #3

RoaddogLabs, 2017-07-15:
replaced carrier, meters voltage at e+ and e-

Closed 2017-07-15.

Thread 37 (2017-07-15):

rpi integration: load cell values not returning to display

RoaddogLabs, 2017-07-15:
cells triggering voltage but not reading in the display

no movement or ramping, showing -1500 on populated cells

check calibration and half bridge circuits

RoaddogLabs, 2017-08-01:
moving from half bridge load cells, won't fix this issue

Closed 2017-08-01.

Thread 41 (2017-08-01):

long sdl12 load on boot

RoaddogLabs, 2017-08-01:
on first boot sdl12 taking 60 secs plus to load

RoaddogLabs, 2017-08-01:
shows 100% cpu utilization for python3 thread

RoaddogLabs, 2017-08-01:
kivy stalls at sdl2 load

RoaddogLabs, 2017-08-01:
runs in sim mode, trying with all load cells connected

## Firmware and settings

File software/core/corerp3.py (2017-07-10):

import sys
import time
from core.loadcell import LoadCell
from core.scaledata import ScaleData


class ScaleControl:
    def __init__(self, interface=None, simulate=False):
        self.interface = interface
        self.load_cells = {'FL': LoadCell(17, 27, simulate=simulate),
                           'FR': LoadCell(22, 23, simulate=simulate),
                           'RL': LoadCell(5, 6, simulate=simulate),
                           'RR': LoadCell(16, 26, simulate=simulate)}

        self.scale_data = {'FL': ScaleData('FL'),
                           'FR': ScaleData('FR'),
                           'RL': ScaleData('RL'),
                           'RR': ScaleData('RR'),
                           'TOTAL': ScaleData('TOTAL', calculated=True),
                           'FLFR': ScaleData('FLFR', calculated=True),
                           'RLRR': ScaleData('RLRR', calculated=True),
                           'FLRR': ScaleData('FLRR', calculated=True),
                           'FRRL': ScaleData('FRRL', calculated=True)}

        self.labels = {'FL': 'FL',
                       'FR': 'FR',
                       'RL': 'RL',
                       'RR': 'RR',
                       'TOTAL': 'TOTAL',
                       'FLFR': 'FRONT',
                       'RLRR': 'REAR',
                       'FLRR': 'FL to RR CROSS',
                       'FRRL': 'FR to RL CROSS'}

    def update(self):
        # get weights from the load cell interface
        self._get_weights()

        # calculate the total weight of all load cells; must always be calculated first
        self._calculate_total()

        # update the corner weights; always calculate total before updating corner weights
        for k in self.load_cells:
            self._calculate_corner(k)

        # update front weight
        self._calculate_pair('FL', 'FR')
        # update rear weight
        self._calculate_pair('RL', 'RR')
        # update front left to rear right cross weight
        self._calculate_pair('FL', 'RR')
        # update front right to rear left cross weight
        self._calculate_pair('FR', 'RL')

        print('FL: ' + str(self.load_cells['FL']),
              'FR: ' + str(self.load_cells['FR']),
              'RL: ' + str(self.load_cells['RL']),
              'RR: ' + str(self.load_cells['RR']))

    def _get_weights(self):
        for k, v in self.load_cells.items():
            v.get_measure()

    def _calculate_total(self):
        total_weight = 0
        self.scale_data['TOTAL'].percent = 100
        for k, v in self.load_cells.items():
            total_weight += v.weight
        self.scale_data['TOTAL'].weight = total_weight
        return total_weight

    def _calculate_corner(self, identifier):
        corner_weight = self.load_cells[identifier].weight
        self.scale_data[identifier].weight = corner_weight
        corner_percent = self.get_percent(corner_weight)
        self.scale_data[identifier].percent = corner_percent
        return corner_weight, corner_percent

    def _calculate_pair(self, identifier1, identifier2):
        identifier = identifier1+identifier2
        pair_weight = self.load_cells[identifier1].weight + self.load_cells[identifier2].weight
        self.scale_data[identifier].weight = pair_weight
        pair_percent = self.get_percent(pair_weight)
        self.scale_data[identifier].percent = pair_percent
        return pair_weight, pair_percent

    def get_percent(self, val1, val2=None):
        if val2 is None:
            val2 = self.scale_data['TOTAL'].weight
        return (val1 / val2) * 100

    def _send_data(self):
        # TODO finish bluetooth implementation so that scale data can be sent to clients
        if self.interface is not None:
            self.interface.send(str(self.scale_data))


if __name__ == '__main__':
    """
    If the core is run by itself then it is headless and needs to set up a BT server for clients to read, conversely if
    the core is run by the local GUI, then the GUI will access the scale controller directly and BT is not started
    """
    # TODO in future the bluetooth server should always be started, then data can be accessed by a client even if local
    # TODO GUI is running. Another option is to always have a local GUI

    import RPi.GPIO as GPIO
    from core.btserver import BluetoothServer
    sc = ScaleControl(BluetoothServer())

    while True:

        try:
            sc.update()
            time.sleep(1)

        except (KeyboardInterrupt, SystemExit):
            GPIO.cleanup()
            sys.exit()

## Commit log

2017-06-26 add schematic and board files for sparkfun pihats
    [pi-hat-v.02-sparkfun.brd, pi-hat-v.02-sparkfun.sch]
2017-06-26 update schematic and board, generate gerbers
    [pi-hat-v.02-sparkfun copy.brd, pi-hat-v.02-sparkfun copy.sch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]
2017-06-27 plate through holes, upload BOM
    [pi-hat-v.02-sparkfun.brd, pi-hat-v.02-sparkfun.sch, pi-hat-v.02-sparkfun_BOM.csv]
2017-06-27 update gerbers
    [pi-hat-v.02-sparkfun.GBL, pi-hat-v.02-sparkfun.GBO, pi-hat-v.02-sparkfun.GBP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]
2017-07-01 bom for first batch of prototypes
    [hx711_main board_BOM.csv]
2017-07-10 update pi-zero board readme
2017-07-10 update Chenbo pi-hat BOM
    update Chenbo pi-hat to move Pi and GPIO header to Pololu to
    consolidate vendors
    [hx711_main board_BOM.csv]
2017-07-13 update Chenbo BOM
    [hx711_main board_BOM.csv]
2017-07-15 update README
    speling…
2017-07-16 add first rev ble dongle hardware
    [ORS-Bluefruit-BLE-Dongle-v0.01.brd, ORS-Bluefruit-BLE-Dongle-v0.01.sch]
2017-07-16 rename ble dir
    [ORS-Bluefruit-BLE-Dongle-v0.01.brd, ORS-Bluefruit-BLE-Dongle-v0.01.sch]

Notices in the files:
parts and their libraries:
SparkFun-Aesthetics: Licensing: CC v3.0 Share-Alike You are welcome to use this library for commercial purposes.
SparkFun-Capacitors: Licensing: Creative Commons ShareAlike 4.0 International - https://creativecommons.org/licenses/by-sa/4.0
